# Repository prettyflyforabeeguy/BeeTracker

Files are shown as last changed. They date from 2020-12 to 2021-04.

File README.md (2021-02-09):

# Bee Tracker
> I created this device to support HoneyBee health through detecting varroa mites and other invaders.  Given the urgency with the Giant Asian Hornet, I've quickly adapted this to detect them as well.  My friend [marlinspike](https://github.com/marlinspike) and I wrote the code in python to bring it altogether.  This app uses TensorFlow machine learning models to perform image classification locally at the device. All telemetry data is sent to **Azure IoT Central**.

### Required Hardware
- [Raspberry Pi Zero W](https://amzn.to/3sxi9aU)  (The pi zero is substantially slower for image recognition, but also consumes way less power.)<br>
	- [Raspberry Pi Powersupply (for Zero or Pi 3)](https://amzn.to/2XO5uCn)<br>
	- [Pi Zero camera ribbon](https://amzn.to/3bTHdmN)<br>
- [Raspberry Pi 3 B+](https://amzn.to/3ilsYYZ)<br>
- [Raspberry Pi 4 (4GB)](https://amzn.to/3qsTfr5)<br>
	- [Raspberry Pi Powersupply (for Pi 4)](https://amzn.to/3ilvDSt)<br>
- [Arducam 5MP camera](https://amzn.to/3oU6hh4)<br>
- [32 GB SD Card](https://amzn.to/3ing7p7)<br>
- [Jumper wires for connecting led and VCNL4010 motion sensor](https://amzn.to/39EB0rX)<br>
- [20 ohm resistor for led](https://amzn.to/3qv0Nty)<br>
- [3v white LED for camera flash](https://amzn.to/2XNUSTV)<br>
**Motion Sensor:**<br>
- [Adafruit VCNL4040 motion sensor](https://www.adafruit.com/product/4161)<br>
	- [Jumper wire for VCNL4040](https://www.adafruit.com/product/4397)<br>
OR<br>
- [Adafruit VCNL 4010 motion sensor](https://www.adafruit.com/product/466)<br>

## Getting Started
### Software Installation (Raspberry Pi3 & Raspberry Pi4)
1. Download Latest version of [Raspberry Pi OS](https://www.raspberrypi.org/software/operating-systems/):
At the time of writing this we're using Kernel version 5.4

2. Install the OS using [Win32 Disk Imager](https://win32diskimager.org/)
3. Booth the Pi and setup all initial configuration:<br>
	- Keyboard, Language, Timezone, Wifi<br>
	- Update the pi (Sudo apt-get update) This might take ~40 - 60min<br>
	- Sudo raspi-config<br>
		   	i. System Option -> HostName -> BeeTracker<br>
		   	ii. Interface Options -> Camera -> Enabled<br>
		  	iii. Interface Options -> SSH -> Enabled<br>
		  	iv. Interface Options -> I2C -> Enabled<br>
		  	v. Finish / Reboot<br>
4. SSH into your new pi
5. mkdir src
6. cd src
7. git clone https://github.com/prettyflyforabeeguy/BeeTracker.git
8. pip3 install -r ~/src/BeeTracker/requirements.txt
9. sudo apt-get install libatlas-base-dev

### Beebooth Assembly
1. Solder the resistor to the Anode side of the led (the slightly longer side) and attach a jumper wire to each end.  I used a little shrink tubing to keep things more tidy but you don't have to do this.
2. Slide the LED into the opening near the top of the booth.  The idea is to bend the LED bulb to be right next to the camera lens to act as a flash.  Careful not to block the camera lens with the LED.<br>
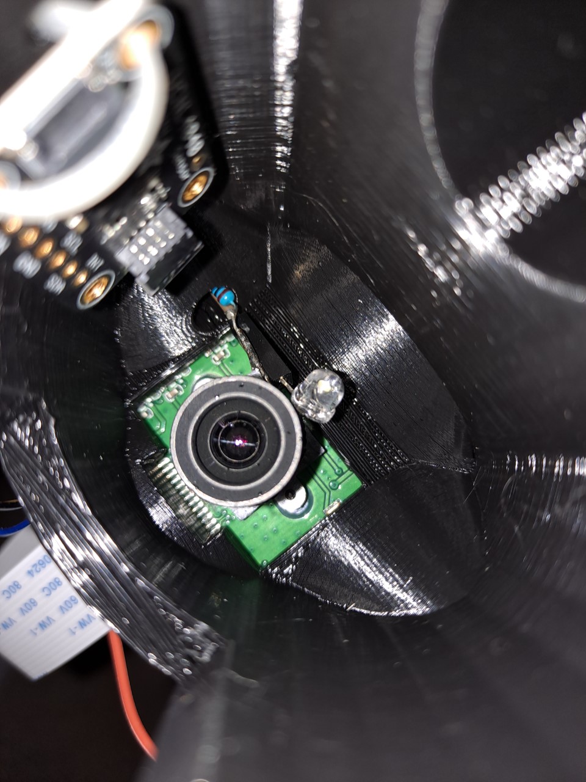
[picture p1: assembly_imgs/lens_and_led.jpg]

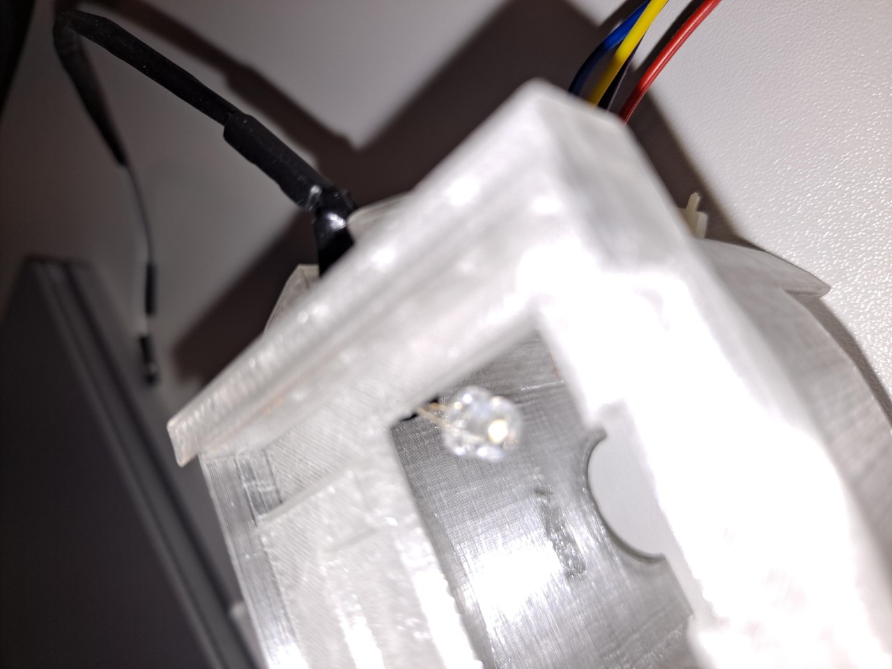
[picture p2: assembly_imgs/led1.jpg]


3. Slip the jumper wires through the slot on the lower right hand side of the booth.  Note it's probably easier to first attach the jumper wires to the sensor before slipping them through.(see wiring instructions below)  Use a small zip tie or hot glue to hold the motion sensor in place.<br>
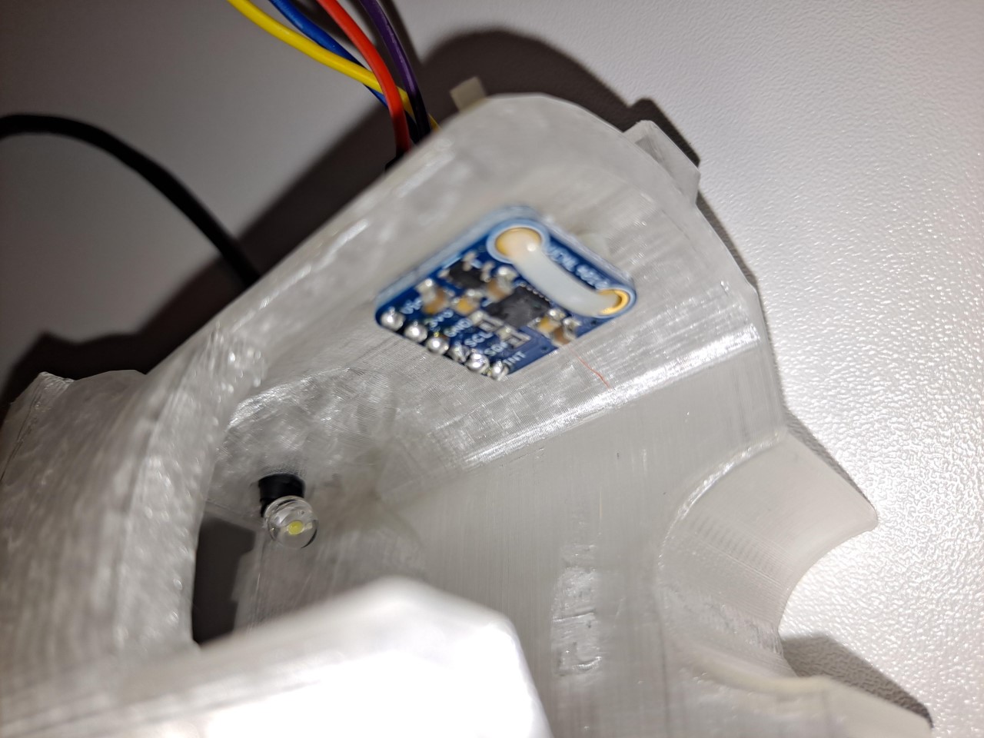
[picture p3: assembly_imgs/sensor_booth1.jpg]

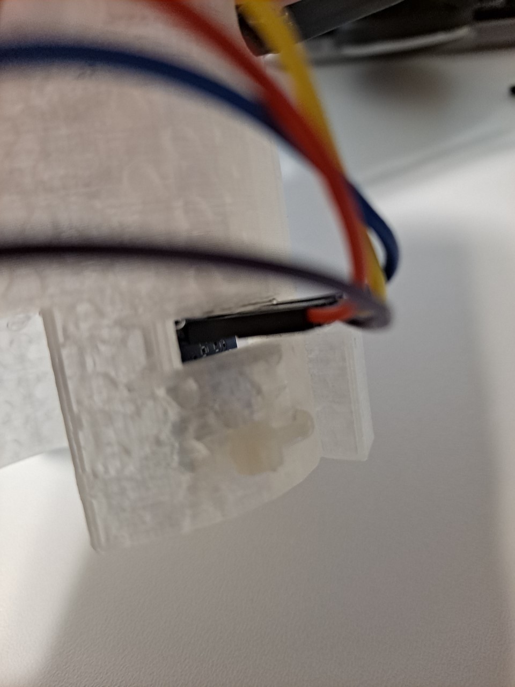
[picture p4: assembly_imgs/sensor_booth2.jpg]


4. Carefully attach the camera ribbon to the camera. Take care to insert the ribbon the proper direction.  Usually the little black slider clip on the camera will be up against the colored strip on the ribbon. 
5. Insert the Arducam face down into the 3D printed bee booth (lens facing into the booth opening). Note the ribbon should be sticking out toward the square opening (the front) of the bee booth
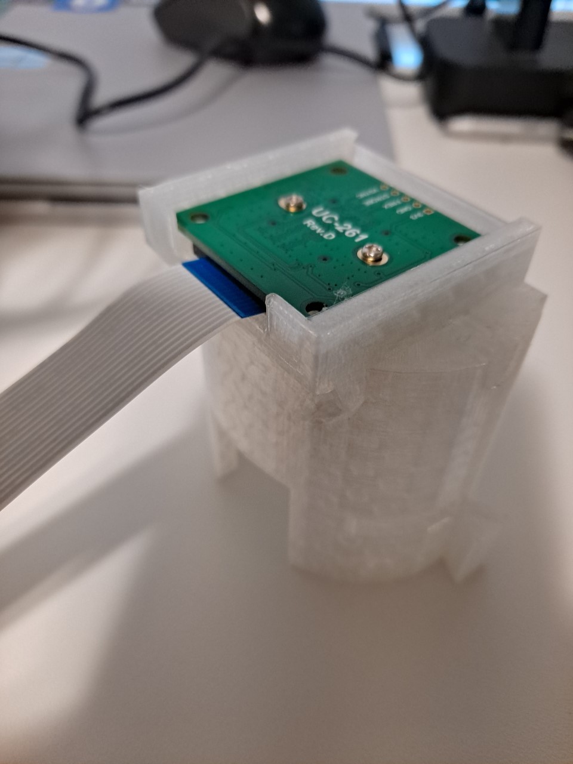
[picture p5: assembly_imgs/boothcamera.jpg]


6. Snap the Raspberry Pi into the 3d printed holder, and slide it into the slot on top of the booth. It should fit all the way forward so the flat pack of the Pi case is flush with the flat back of the bee booth.
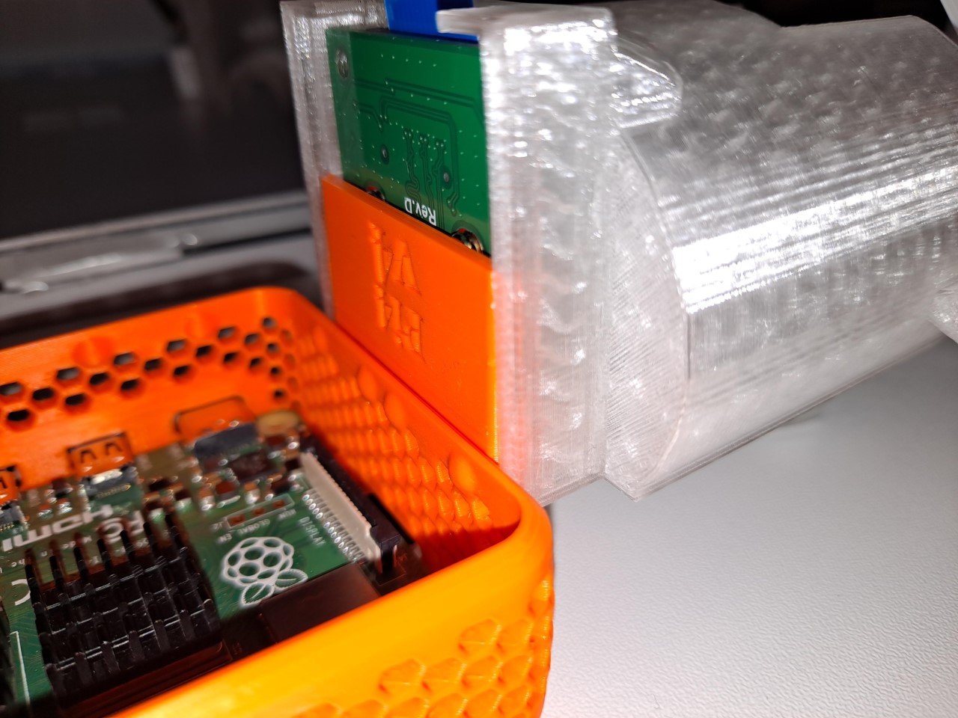
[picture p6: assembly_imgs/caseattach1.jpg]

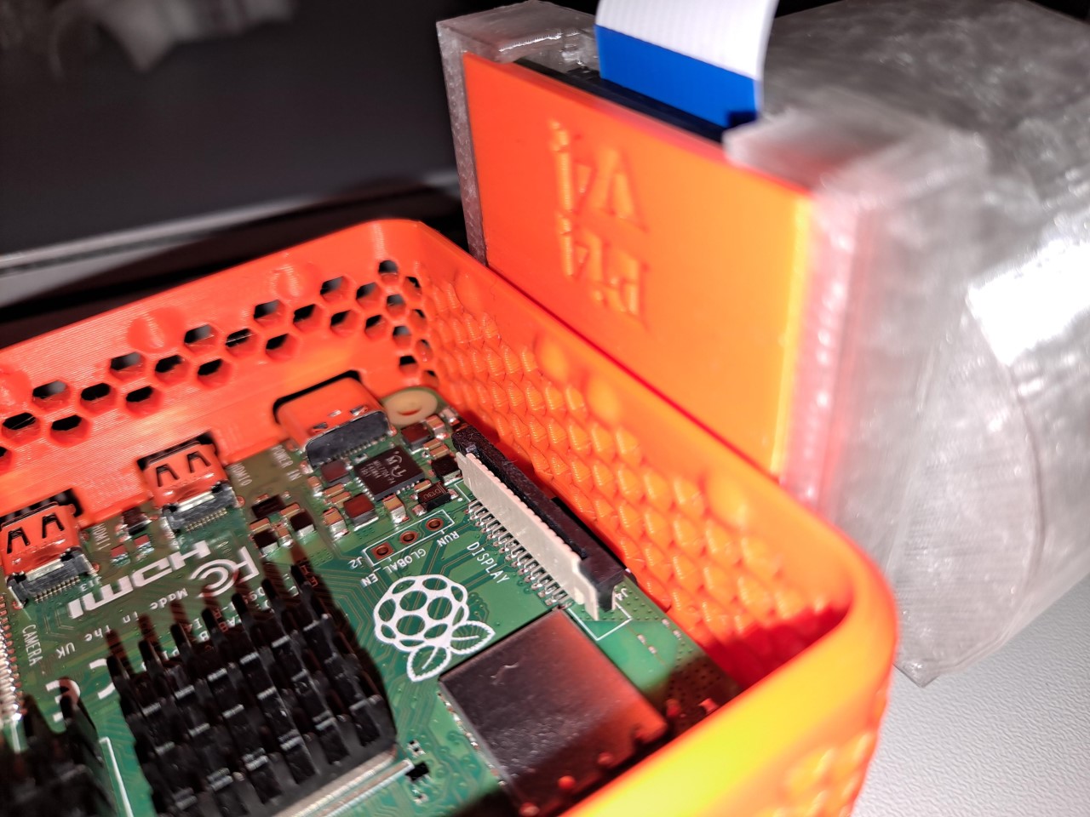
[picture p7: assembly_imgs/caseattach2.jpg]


7. Attach the camera ribbon to the Raspberry Pi
8. Attach a jumper wire to the cathode (short end) from the LED to pin14 (Ground) on the Pi and the anode (long end  with resistor) with a jumper wire to pin16 (GPIO23) on the pi.

### Hardware wiring
For the VCNL 4010 Sensor:
1. Attach the red wire to the Vin pin on the sensor, and connect the other end to pin 1 on the Raspberry Pi (3.3v)
2. Attach the black wire to the GND pin on the sensor, and connect the other end to 9 on the Raspberry Pi (Ground)
3. Attach the blue wire to the SCL pin on the sensor, and connect the other end to pin 5 on the Raspberry Pi (GPIO3)
4. Attach the Yellow wire to the SDA pin on the sensor, and connect the other end to pin 3 on the Raspberry Pi (GPIO2)
5. 3vo and INT pins are not used on the motion sensor.  
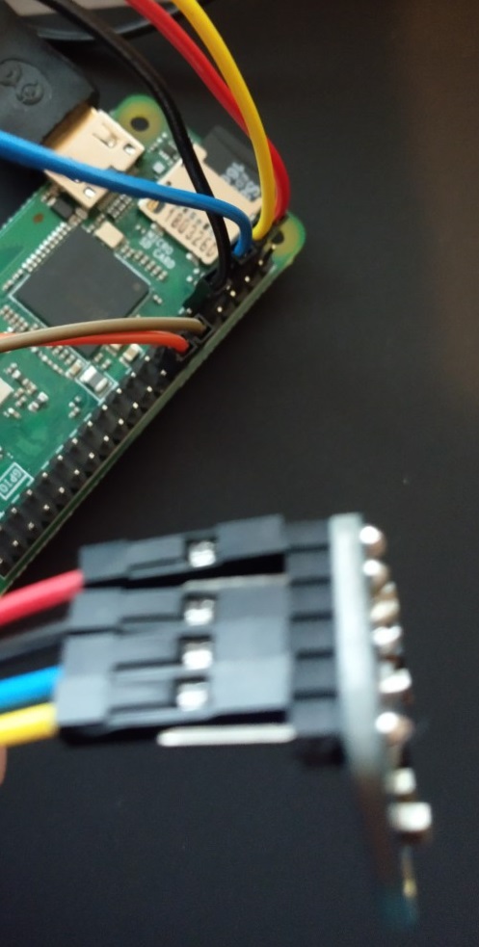
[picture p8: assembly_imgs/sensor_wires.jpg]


### Hardware wiring
For the VCNL 4040 Sensor:
6. Attach the 4 pin female to female pin to either socket on the motion sensor
7. Attach the red wire to the Vin pin on the sensor, and connect the other end to pin 1 on the Raspberry Pi (3.3v)
8. Attach the black wire to the GND pin on the sensor, and connect the other end to 9 on the Raspberry Pi (Ground)
9. Attach the blue wire to the SCL pin on the sensor, and connect the other end to pin 3 on the Raspberry Pi (GPIO2)
10. Attach the Yellow wire to the SDA pin on the sensor, and connect the other end to pin 5 on the Raspberry Pi (GPIO3)
11. Note the blue and yellow wires are in reversed positions compared to using the VCNL4010 sensor.<br>
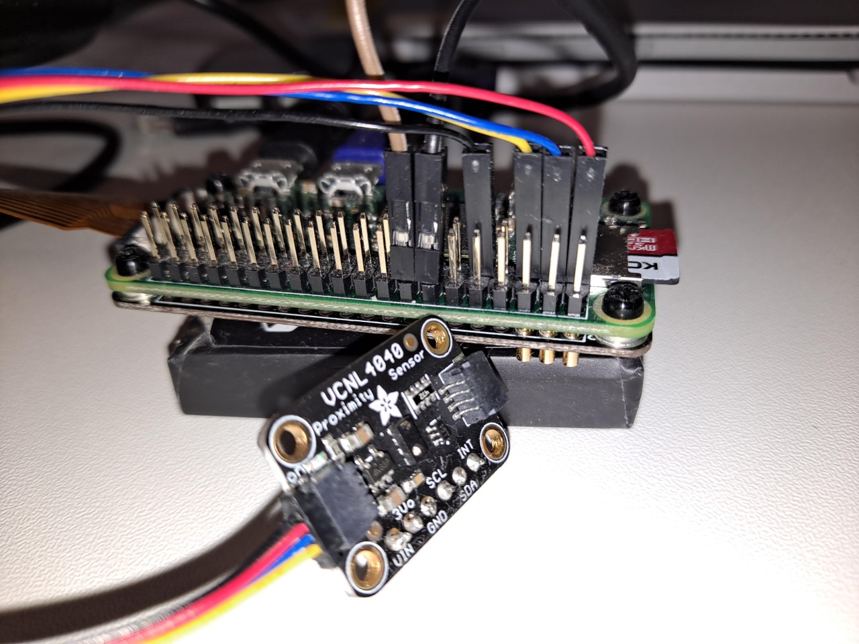
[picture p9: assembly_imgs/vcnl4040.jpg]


Once everything is attached should look something like this:<br>
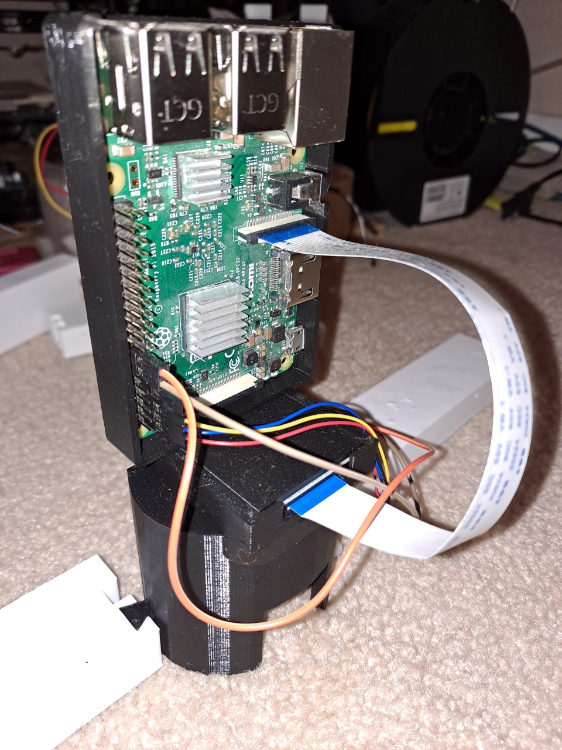
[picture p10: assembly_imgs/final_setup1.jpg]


If you want to add the weather protection cover it should slip right over everything like this:<br>
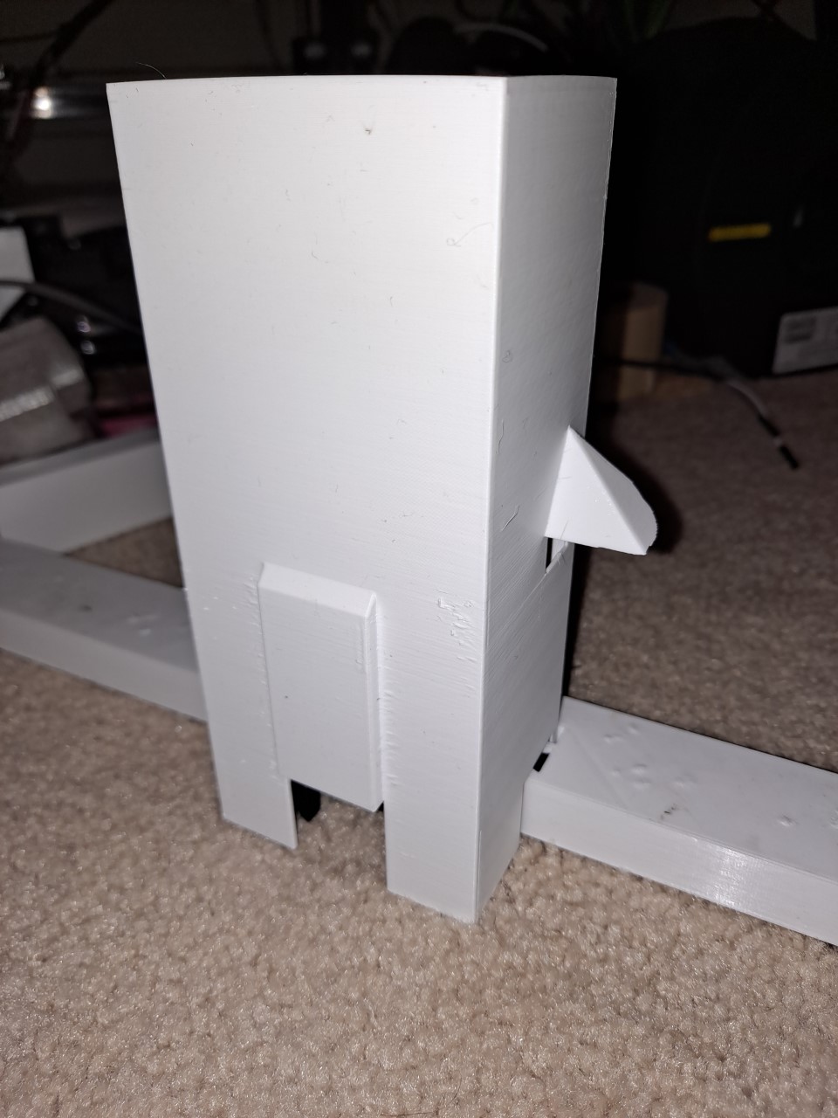
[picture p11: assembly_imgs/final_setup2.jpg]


### Azure Resources Required
- Azure IoT Hub: Your device will need to be enrolled, and it's connection string updated in the **creds.json** file discussed below
- Azure Storage: Optionally used to archive telemetry data from the device
- Azure Stream Analytics: Optionally used for telemetry analysis 

### Configuring the Credentials file (creds.json)
This app needs a **creds.json** file to store certain required credential and status info. It's not contained in the repo for obvious reasons.  If you want to connect to our global dashboard please contact me separately so your device can be added.
here's the structure you'll need:

```json
{
    "device_id" : "CommunityDevicesFromGithub",
    "latitude" : "",
    "longitude" : "",
    "owner_email" : "",
    "provisioning_host": "global.azure-devices-provisioning.net",
    "registration_id": "CommunityDevicesFromGithub",
    "id_scope": "0ne00146FA6",
    "symmetric_key": "Please Contact me for this public dashboard key",
    "blob_token": "",
    "tf_models": ""
}
```
Save this in a file called **creds.json** in the root folder of the application.

## Download the tensor flow models
You'll want to download both the Tier1 and Tier2 models and save them in BeeTracker/tier1 and BeeTracker/teir2 accordingly.
As our community grows, we'll have new image data to further improve the training of these learning models and will publish updated versions.<br>
TIER1: https://1drv.ms/u/s!Aok2ArNyzY-zvSVIRDXiCsHZr5i3?e=CafR22 <br>
TIER2: https://1drv.ms/u/s!Aok2ArNyzY-zvSbGrdxlGFCBOBW1?e=veEdGo <br>

## Running the app
Depending which sensor you're using, run the app using the command:
```bash
 python3 motion.py --sensor vcnl4010
 python3 motion.py --sensor vcnl4040
 ```
There are options to upload your images to a cloud storage container.  This is disabled by default.
If you enable this, your images will contribute to future model training.

Note that the initial startup time for the app is approx 30-45 seconds, as it loads the TensorFlow model. Performing image classification on the first image takes substantially longer (30s), than every subsequent image (1.1s).

## Running in TEST Mode
Test mode tells the app to use the sample images in the **img_test** folder instead of ones it takes with the camera. These images are not ones used to train the model used, but ones that will test the classification and allow the app to run without the need for Bees to look at!

**To run in TEST Mode:**
```bash
Python3 motion.py --test True
```

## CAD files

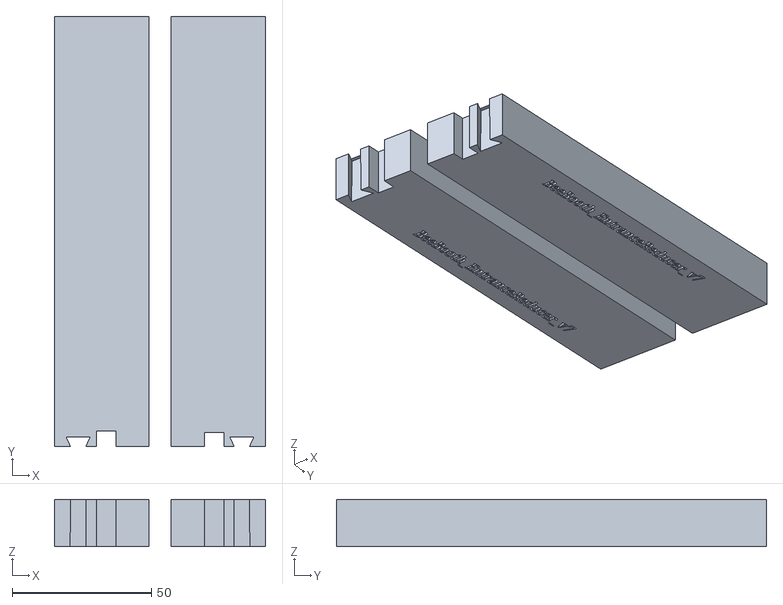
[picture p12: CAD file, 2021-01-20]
STL_Files/BeeBooth_EntranceReducers_v7.stl
75.8 x 154.5 x 17.0

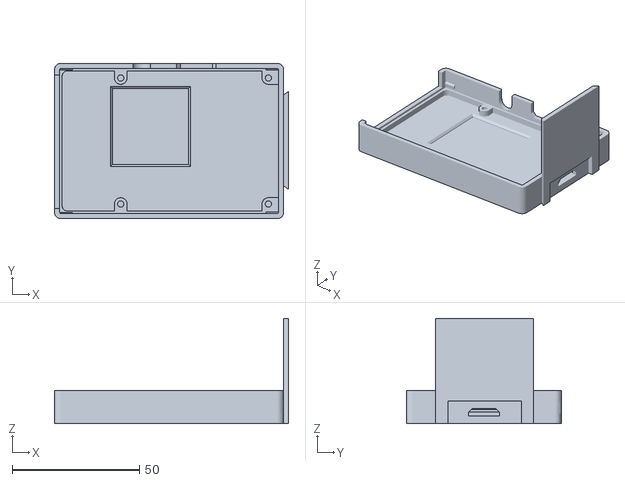
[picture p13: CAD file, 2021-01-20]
STL_Files/Pi3/Beebooth_Pi3_holder_v6.stl
91.9 x 61.0 x 41.4

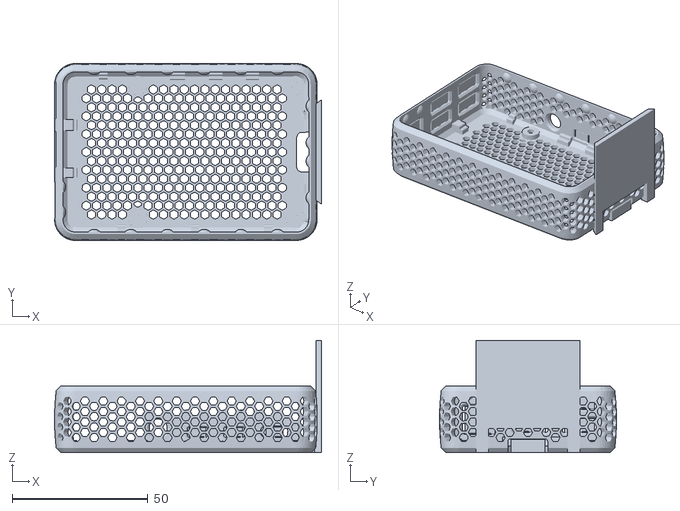
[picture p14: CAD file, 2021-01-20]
STL_Files/Pi4/Beebooth_Pi4_holder_v4.stl
98.4 x 65.2 x 41.4

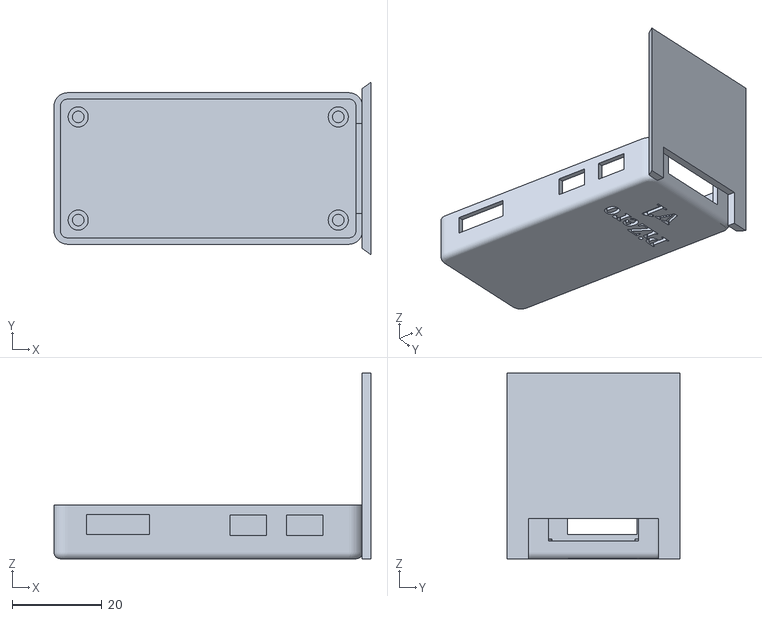
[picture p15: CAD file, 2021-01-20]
STL_Files/Pi_ZeroW/Beebooth_PiZero_holder_v1.stl
70.7 x 38.5 x 41.4

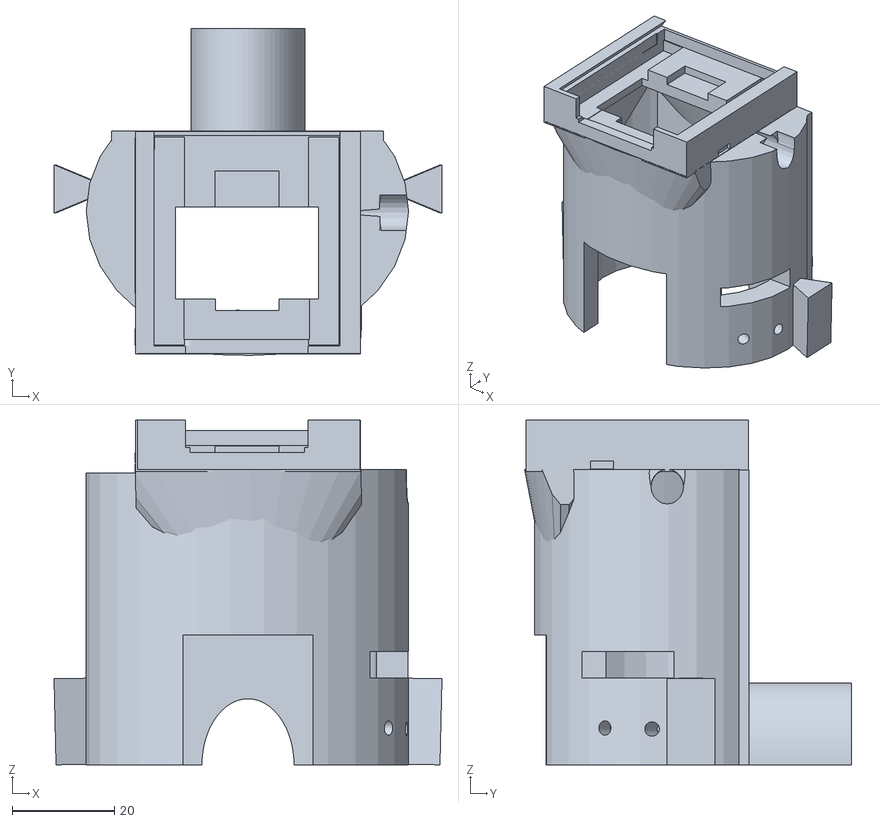
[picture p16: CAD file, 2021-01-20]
STL_Files/BeeBooth_Base_FishEyeCamera_v15.stl
75.9 x 63.9 x 67.4

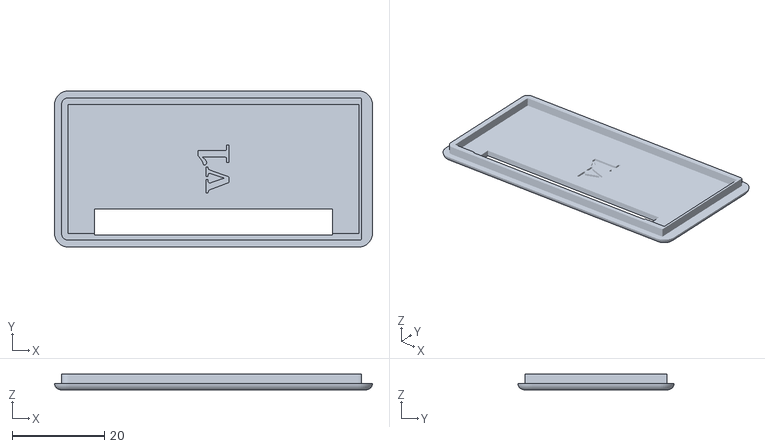
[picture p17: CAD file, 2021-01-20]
STL_Files/Pi_ZeroW/BeeBooth_PiZero_cover_v1.stl
68.8 x 33.8 x 3.40

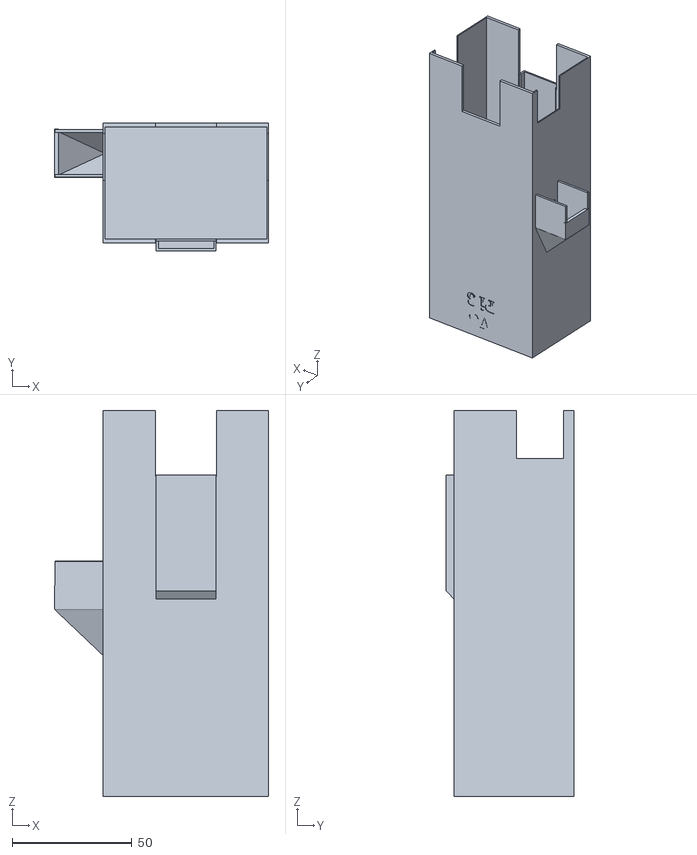
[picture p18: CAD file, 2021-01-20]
STL_Files/BeeBooth_WeatherCover_Pi3_v3.stl
89.4 x 53.2 x 161.0

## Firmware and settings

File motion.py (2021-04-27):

import RPi.GPIO as GPIO
from gpiozero import MotionSensor, LED
from RCamera import RCamera
from credentials import Credentials
from azure.iot.device.aio import IoTHubDeviceClient
from datetime import datetime
from utils import CredentialInfo
from message_payload import MessagePayload
from tf_classify import TFClassify
from tf_classify2 import TFClassify2
import sys, json, logging, argparse, app_logger, asyncio, signal, os
import device_connect_service
from iotc.aio import IoTCClient
from iotc import IOTCConnectType, IOTCLogLevel, IOTCEvents
import iot_events.device_events as device_events
from app_settings import AppSettings
import iot_events.iot_commands as iot_commands
import busio, board       #needed for i2c interface with proximity sensors
import adafruit_vcnl4040  #needed for the vcnl4040 proximity sensor
import adafruit_vcnl4010  #needed for the vcnl4010 proximity sensor
import time
from azure.storage.blob import BlobServiceClient, BlobClient, ContainerClient

#Define some globals
GPIO.setmode(GPIO.BCM)
camera = RCamera()  #Camera connected to camera pins
credentials: Credentials = Credentials()
device_client: IoTCClient = None #IoTHubDeviceClient.create_from_connection_string(credentials.get_credentail_info(CredentialInfo.connection_string))
start_time = datetime.now()
tfclassifier = TFClassify()
tfclassifier2 = TFClassify2()
log:logging.Logger = app_logger.get_logger()
log.info(f"TensorFlow took {datetime.now() - start_time} seconds to load")

modelTier = "tier1"
_app_settings = AppSettings()
_app_settings.ensure_label_folders_exist(modelTier)

modelTier2 = "tier2"
_app_settings2 = AppSettings()
_app_settings.ensure_label_folders_exist(modelTier2)

# Set the trigger word for setting a sub tier model lookup
_subTierTrigger = _app_settings.get_SubTierTrigger(modelTier)
_subTierTrigger2 = _app_settings2.get_SubTierTrigger(modelTier2)

_USE_TEST_MODE = False
_USE_BLOB_STORGE = False

#_app_settings = AppSettings()
#These commands are sent by IoT Central to the device
_IoT_Commands = {
    'DownloadModel': iot_commands.iot_download_model,
    'UploadImages': iot_commands.iot_upload_images,
    'Blink': iot_commands.iot_blink
}

async def send_iot_message(message=""):
    await device_events.send_iot_message(device_client, message)

# Connect to storage acccount
def connect_storage_account():
    global tier1_container
    global blob_service_client
    with open("./blob_config.json") as json_data_file:
        data = json.load(json_data_file)
        connection_str = data["blob"]["connection_string"]
        tier1_container = data["blob"]["tier1_container"]
    try:
        blob_service_client = BlobServiceClient.from_connection_string(connection_str)
    except Exception as e:
        log.error("Exception in get_storage_account_details(): {e}")
        print("Exception in get_storage_account_details(): " + e)

# Send image to Azure Storage Blob
def upload_to_storage_account(blob_service_client, container_name, img_file):
    try:
        # Create a blob client using the local file name as the name for the blob
        blob_client = blob_service_client.get_blob_client(container=container_name, blob=img_file)

        print("\nUploading to Azure Storage as blob:\n\t" + img_file)

        # Upload the created file
        cwd = os.getcwd()
        upload_file_path = cwd + "/" + img_file
        with open(upload_file_path, "rb") as data:
            blob_client.upload_blob(data)
    except Exception as e:
        log.error("Exception in upload_to_storage_account(): {e}")
        print("Exception in upload_to_storage_account(): " + e)


# Calibrate the proximity sensor
def calibratePSensor(vcnl):
    print("Calibrating Proximity Sensor...")
    percent = None
    motionSense=[]
    for i in range (3):
        proximity = vcnl.proximity
        print("Proximity: {0}".format(proximity))
        motionSense.append(proximity)
        time.sleep(1)

    avg = sum(motionSense) / len(motionSense)
    print("Average Proximity: " + str(avg))
    # Increase average proximity by 2% as "motion"
    percent = avg + (avg * .02)
    print("Plus 2%: " + str(percent))
    return percent


async def movement_detected():
    global start_time, _USE_TEST_MODE
    log.info("Movement Detected!")
    if args.sensor == 'motion':
        red_led.on()
    # Take a picture and save it to the folder specified; "" for current folder
    flash_led.on()
    pic_info = camera.take_picture("img/", credentials.get_credentail_info(CredentialInfo.device_id), _USE_TEST_MODE)
    flash_led.off()
    picture_name = pic_info[1]
    tfclassifier.reset()
    tfclassifier.addImage(picture_name)
    start_time = datetime.now()
    picture_classification = tfclassifier.doClassify()
    log.info(f"Image Classification took {datetime.now() - start_time} seconds")
    #Only send telemetry if we see one of the classifications we care about; else, delete the photo
    valid_labels = _app_settings.get_TFLabels(modelTier) # Labels classified
    #print(picture_classification)
    if ((picture_classification[0]['Prediction'] in valid_labels)): #See appsettings.json ["Honeybee", "Invader", "Male Bee"]):
        message = f"{picture_classification[0]}"
        os.rename(picture_name, os.path.join("img", picture_classification[0]['Prediction'].__str__(), picture_classification[0]['Prediction'] + "_" + pic_info[0])) 
        picture_name =  os.path.join("img", picture_classification[0]['Prediction'].__str__(),picture_classification[0]['Prediction'] + "_" + pic_info[0])
        #asyncio.run(send_iot_message(message))
        await send_iot_message(message)
        if(_USE_BLOB_STORAGE):
            container_name = tier1_container
            #upload the image to Azure
            upload_to_storage_account(blob_service_client, container_name, picture_name)
    if ((picture_classification[0]['Confidence'] > 0.60) and _USE_TEST_MODE == False):
        if os.path.exists(picture_name):
            print(f"Removing {picture_name}")
            os.remove(picture_name)

    if (picture_classification[0]['Prediction'] == _subTierTrigger):
        log.info("Checking model sub tier.")
        tfclassifier2.reset()
        tfclassifier2.addImage(picture_name)
        start_time = datetime.now()
        picture_classification = tfclassifier2.doClassify()
        log.info(f"Tier2 Image Classification took {datetime.now() - start_time} seconds")
        valid_labels = _app_settings.get_TFLabels(modelTier2) # Labels classified
        if ((picture_classification[0]['Prediction'] in valid_labels)): 
            message = f"{picture_classification[0]}"
            os.rename(picture_name, os.path.join("img", picture_classification[0]['Prediction'].__str__(), picture_classification[0]['Prediction'] + "_" + pic_info[0])) 
            picture_name =  os.path.join("img", picture_classification[0]['Prediction'].__str__(),picture_classification[0]['Prediction'] + "_" + pic_info[0])
            await send_iot_message(message)
        print("Done!")
    
    if (_DELETE_IMAGES):
        if os.path.exists(picture_name):
            print(f"Removing {picture_name}")
            os.remove(picture_name)

#No-movement detected method
async def no_movement_detected():
    log.info("No movement...")
    red_led.off()

#Clean up
def destroy():
    try:
        tfclassifier = None
        camera = None
        GPIO.cleanup()  # Release GPIO resource
    except Exception as e:
        log.info(f"Exiting..")
        sys.exit(0)


#Main app loop.
async def main_loop():
    global _IoT_Commands
    global device_client
    global percent
    global proximity

    try:
        device_client = await device_connect_service.connect_iotc_device()
        if(args.sensor == 'motion'):
            move_sensor.when_motion = movement_detected
            move_sensor.when_no_motion = no_movement_detected
    except Exception as e:
        log.error("Exception in main_loop: {e}")
        print("Exeption in main_loop: " + e)
        pass

    print("Ready to detect motion...")
    while True:
        try:
            if(args.sensor == 'vcnl4010' or args.sensor == 'vcnl4040'):
                proximity = vcnl.proximity
                if proximity >= percent:
                    await movement_detected()
            else:
                method_request = await device_client.receive_method_request()
                await _IoT_Commands[method_request.name](method_request, device_client, credentials)
        except KeyboardInterrupt as kbi:
            log.error("KeyboardInterrupt: {kbi}")
            GPIO.cleanup()
            sys.exit(0)
        except Exception as e:
            log.error("Exception in main_loop: {e}")
            print("Exception in main_loop: " + e)
            GPIO.cleanup()
            sys.exit(0)

async def main():
    global device_client
    start_time = datetime.now()
    log.info(f"Ready! Starting took {datetime.now() - start_time} seconds")

def signal_handler(signal, frame):
    destroy()
    sys.exit(0)

def startup():
    asyncio.run(main())
    signal.signal(signal.SIGINT, signal_handler)
    log.info("Starting main loop")
    asyncio.run(main_loop())

if __name__ == '__main__':
    # Welcome Message
    print("**************************************************************************")
    print("**  Welcome to Beetracker!                                              **")
    print("**  Supported sensors: vcnl4010, vcnl4040, and motion                   **")
    print("**************************************************************************")
    log.info('Starting...')
    parser = argparse.ArgumentParser()
    parser.add_argument('--test', required=False, help="Enable test mode")
    parser.add_argument('--sensor', required=False, action='store', dest='sensor', choices=['vcnl4010','vcnl4040', 'motion'], help="Select a Motion or Proximity Sensor")
    parser.add_argument('--blobstorage', required=False, help="Enable blob storage")
    parser.add_argument('--deleteimages', required=False, help="Delete images after classifcation if true")
    args = parser.parse_args()
    _USE_TEST_MODE = args.test
    _USE_BLOB_STORAGE = args.blobstorage
    _DELETE_IMAGES = args.deleteimages
    if (_USE_TEST_MODE):
        log.info("Starting in TEST Mode")
    if (_USE_BLOB_STORAGE):
        log.info("Blob Storage Enabled.")
        connect_storage_account()
    if (_DELETE_IMAGES):
        log.info("Deleting images after classification.")
    if args.sensor == 'vcnl4010':
            log.info("Calibrating VCNL4010 motion sensor")
            i2c = busio.I2C(board.SCL, board.SDA)
            vcnl = adafruit_vcnl4010.VCNL4010(i2c)
            percent = calibratePSensor(vcnl)
            flash_led = LED(23)   #LED connected on GPIO pin 23
    if args.sensor == 'vcnl4040':
            log.info("Calibrating VCNL4040 motion sensor")
            i2c = busio.I2C(board.SCL, board.SDA)
            vcnl = adafruit_vcnl4040.VCNL4040(i2c)
            percent = calibratePSensor(vcnl)
            flash_led = LED(23)   #LED connected on GPIO pin 23
    if args.sensor == 'motion':
            log.info("Using Motion Sensor")
            move_sensor = MotionSensor(17)  #Motion Sensor control connected to GPIO pin 17
            red_led = LED(18)   #LED connected to GPIO pin 18

    try:
        startup()
    except SystemExit:
        pass
    finally:
        GPIO.cleanup()
        sys.exit(0)

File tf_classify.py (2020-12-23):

import time
from lobe import ImageModel
#from lobe.signature import Signature
from lobe.signature import ImageClassificationSignature
import lobe
from app_settings import AppSettings

modelTier = "tier1"
_app_settings = AppSettings()

sigpath = _app_settings.get_SignaturePath(modelTier)
#sig:Signature = Signature(sigpath)
sig: ImageClassificationSignature = ImageClassificationSignature(sigpath)

#sig:Signature = Signature('./tf_models_lite/tier1/signature.json')
model: ImageModel = ImageModel.load_from_signature(sig)

#test_model: ImageModel = ImageModel.load_from_signature(Signature('./tf_models_lite/sig.json'))
#model_not_a_bee: ImageModel = ImageModel.load()

'''
The TFClassify class (Tensor Flow Classifier), takes a TensorFlow model and allows you
to pass multiple images to it via the addImage() or addImages() methods. It then
returns the predicted classification of the images as a DICT array
{
    'image': '<image_path_sent_to_classifier>',
    'prediction': 'output_prediction_from_TensorFlow'>
}
'''
class TFClassify:
    def __init__(self):
        self.images = []
        self.results = []

    #Add a single image to the classifier
    def addImage(self, imagePath) -> int:
        self.images.append(imagePath)
        return len(self.images)
    #Add an array of images to the classifier
    def addImages(self, imagePaths:[]) -> int:
        self.images = imagePaths
        return len(self.images)

    #Clears the image array
    def reset(self):
        self.images, self.results = [], []

    def create_json_result(self, prediction, image_path, confidence="X"):
        calc_val = lambda prediction, item: 1 if prediction == item else 0
        valid_labels = _app_settings.get_TFLabels(modelTier)
        #IoT Central maps these keys to specific values in the JSON Response. Need to match
        dicList = {k: v for (k, v) in zip(valid_labels, valid_labels)}
        result = {
            "Confidence": confidence,
            "Prediction": prediction,
            "Image": image_path
        }
        for key, value in dicList.items():
            if key == prediction:
                result[value] = 1
            else:
                result[value] = 0
        return result


    '''For each image in the images collection, process it, and then return
        an array of results. Each item in the array is a dictionary:
        {image:<image_path>, prediction:<prediction_from_tensorflow>}
    '''
    def doClassify(self) -> []:
        for item in self.images:
            res = model.predict_from_file(item)
            predict, confidence = res.labels[0]
            result = self.create_json_result(predict, item, confidence)
            self.results.append(result)
        return self.results



if __name__ == '__main__':
    classifier = TFClassify()
    classifier.reset()
    classifier.addImage('tf_models/1.jpeg')
    classifier.addImage('tf_models/2.jpeg')
    results = classifier.doClassify()
    for r in results:
        print(r)

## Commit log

2021-01-17 Adding STL Files
    Adding STL Files
    [BeeBooth_Base_FishEyeCamera_v15.stl, BeeBooth_EntranceReducers_v7.stl, BeeBooth_PiZero_cover_v1.stl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]
2021-04-27 Added a commandline arg to not save images on the local pi. The SD card was filling too fast. Still need to work with the storage blob connection time outs after long quite periods of no bee activity.
    [motion.py]
